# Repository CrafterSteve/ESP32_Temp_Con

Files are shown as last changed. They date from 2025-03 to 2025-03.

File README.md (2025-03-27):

# ESP32_Temp_Con
An temperture control device, based on ESP32. With custom PCB board, it can fit an ESP32-DevKit as controller, DAC and ADC is done on board, as well as, a 5 to +-12v power supply.

## Notes:
项目中 ./main/my_spiffs/ 目录下的文件会通过命令，全部烧写的分区 label 的 flash 中。

创建自定义空间前，先做配置：
used "idf.py menuconfig" to change partition table to csv.

created "partitions.csv" with 256KB of spiffs as "/storage": （以下是"partitions.csv"文件应该包含的内容）
nvs, data, nvs, 0x9000, 0x6000
phy_init, data, phy, 0xf000, 0x1000
factory, app, factory, 0x10000, 0x100000
storage, data, spiffs, 0x110000, 0x40000

## SPIFFS指令：
使用时注意 python 工具的路径。“./” 代表本项目的根目录

python D:\esp\v5.2.1\esp-idf\components\partition_table\gen_esp32part.py .\partitions.csv .\partitions.bin                                      // 从csv生成分区文件

idf.py partition-table-flash                                                                                                                    // 烧录分区文件

python D:\esp\v5.2.1\esp-idf\components\spiffs\spiffsgen.py 0x40000 D:\esp_projects\dactest_2.1\main\my_spiffs my_spiffs_img                    // 创建SPIFFS镜像文件

python D:\esp\v5.2.1\esp-idf\components\partition_table\parttool.py -p COM3 write_partition --partition-name storage --input .\my_spiffs_img    // 写入esp32

## 程序调用
in code: base_path = "/storage"     // esp32内文件目录
"/storage/bmp_test.bmp" 为存入的文件
FILE *file = fopen("/storage/bmp_test.bmp", "rb");  // 如此打开flash上的文件
可通过 esp_spiffs_info(spiffs_conf.partition_label, &total, &used); 查看占用，检查是否写入。

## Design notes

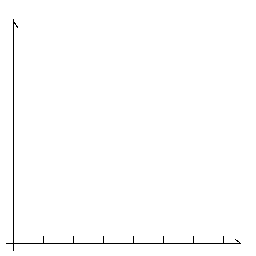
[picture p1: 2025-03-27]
main/my_spiffs/bmp_3.bmp

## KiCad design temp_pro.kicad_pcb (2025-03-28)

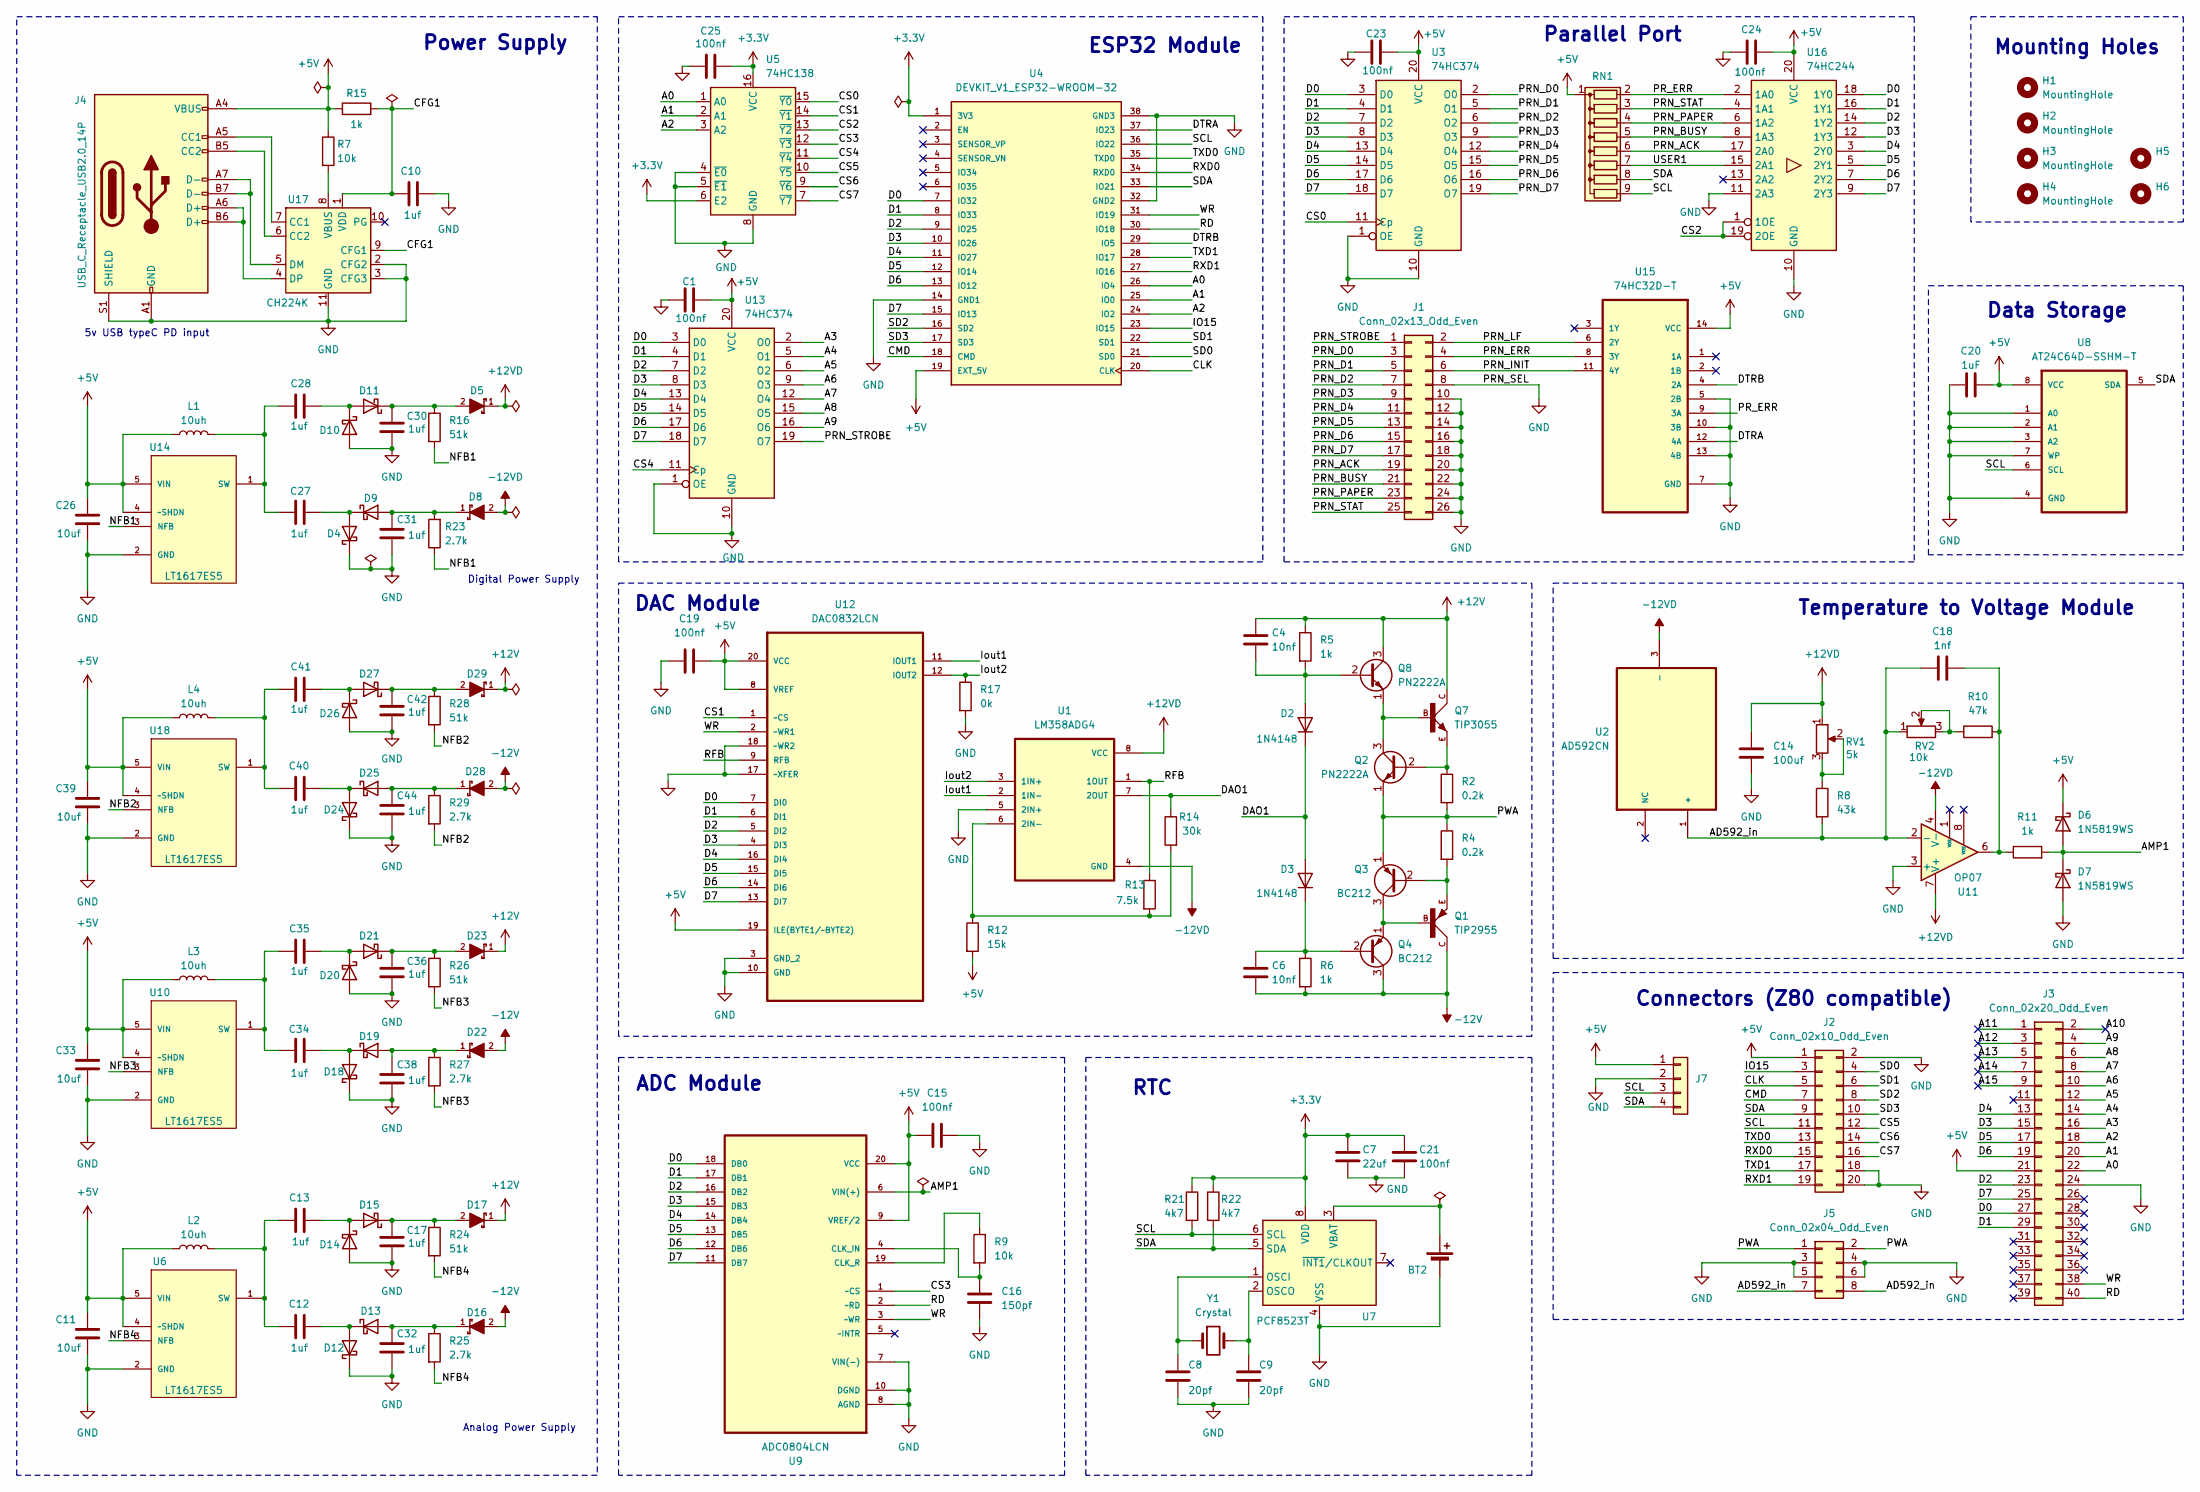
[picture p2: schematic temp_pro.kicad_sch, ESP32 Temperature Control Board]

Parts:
BT2: Battery_Cell; TE_796136-1
C1, C15, C19, C23, C24, C25: 100nf; C_0805_2012Metric
C4, C6: 10nf; C_Disc_D5.0mm_W2.5mm_P5.00mm
C7: 22uf; C_0805_2012Metric
C8, C9: 20pf; C_0805_2012Metric
C10: 1uf; C_0603_1608Metric
C11, C26, C33, C39: 10uf; C_0603_1608Metric
C12, C13, C17, C27, C28, C30, C31, C32, C34, C35, C36, C38, C40, C41, C42, C44: 1uf; C_0805_2012Metric
C14: 100uf; C_0805_2012Metric
C16: 150pf; C_0603_1608Metric
C18: 1nf; C_0805_2012Metric
C20: 1uF; C_0603_1608Metric
C21: 100nf; C_0603_1608Metric
D2, D3: 1N4148; D_DO-35_SOD27_P7.62mm_Horizontal
D4, D9, D10, D11, D12, D13, D14, D15, D18, D19, D20, D21, D24, D25, D26, D27: 1N5822; DIOM5025X220N
D5, D8, D16, D17, D22, D23, D28, D29: SS54-HF; DIOM5025X220N; MOUSER_PART_NUMBER 750-SS54-HF
D6, D7: 1N5819WS; D_SOD-323_HandSoldering
H1, H2, H3, H4, H5, H6: MountingHole; MountingHole_3.2mm_M3_ISO14580
J1: Conn_02x13_Odd_Even; PinHeader_2x13_P2.54mm_Vertical
J2: Conn_02x10_Odd_Even; PinHeader_2x10_P2.54mm_Vertical
J3: Conn_02x20_Odd_Even; PinHeader_2x20_P2.54mm_Vertical
J4: USB_C_Receptacle_USB2.0_14P; USB_C_Receptacle_GCT_USB4105-xx-A_16P_TopMnt_Horizontal
J5: Conn_02x04_Odd_Even; PinHeader_2x04_P2.54mm_Vertical
J7: Conn_01x04; PinHeader_1x04_P2.54mm_Vertical
L1, L2, L3, L4: 10uh; L_Bourns_SRP7028A_7.3x6.6mm
Q1: TIP2955; TOP3AV
Q2, Q8: PN2222A; TO-92_Inline
Q3, Q4: BC212; TO-92_Inline
Q7: TIP3055; TOP3AV
R2, R4: 0.2k; R_Axial_DIN0516_L15.5mm_D5.0mm_P20.32mm_Horizontal
R5, R6: 1k; R_Axial_DIN0207_L6.3mm_D2.5mm_P7.62mm_Horizontal
R7, R9: 10k; R_0603_1608Metric
R8: 43k; R_0805_2012Metric
R10: 47k; R_0805_2012Metric
R11, R15: 1k; R_0805_2012Metric
R12: 15k; R_0805_2012Metric
R13: 7.5k; R_0805_2012Metric
R14: 30k; R_0805_2012Metric
R16, R24, R26, R28: 51k; R_0603_1608Metric
R17: 0k; R_0603_1608Metric
R21, R22: 4k7; R_0603_1608Metric
R23, R25, R27, R29: 2.7k; R_0603_1608Metric
RN1: R_Network08; R_Array_SIP9
RV1: 5k; Potentiometer_Vishay_T93YA_Vertical
RV2: 10k; Potentiometer_Vishay_T93YA_Vertical
U1: LM358ADG4; DIP-8_W7.62mm_Socket
U2: AD592CN; TO-92L; MPN AD592CN
U3, U13: 74HC374; DIP-20_W7.62mm_Socket
U4: DEVKIT_V1_ESP32-WROOM-32; MODULE_DEVKIT_V1_ESP32-WROOM-32; PARTREV N/A
U5: 74HC138; DIP-16_W7.62mm_Socket
U6, U10, U14, U18: LT1617ES5; SOT-23-6; MPN LT1617ES5#PBF
U7: PCF8523T; SOIC-8_3.9x4.9mm_P1.27mm
U8: AT24C64D-SSHM-T; DIP-8_W7.62mm_Socket; MPN AT24C64D-SSHM-T
U9: ADC0804LCN; DIP-20_W7.62mm_Socket; MPN ADC0804LCN
U11: OP07; DIP-8_W7.62mm_Socket
U12: DAC0832LCN; DIP-20_W7.62mm_Socket; MPN DAC0832LCN
U15: 74HC32D-T; DIP-14_W7.62mm_Socket; MPN 74HC32D-T
U16: 74HC244; DIP-20_W7.62mm_Socket
U17: CH224K; SSOP-10-1EP_3.9x4.9mm_P1mm_EP2.1x3.3mm
Y1: Crystal; Crystal_C38-LF_D3.0mm_L8.0mm_Horizontal

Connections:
+3.3V: C7.1, C21.1, C25.2, R21.1, R22.1, U4.1 (3V3), U5.6 (E2), U5.16 (VCC), U7.8 (VDD)
+5V: C1.2, C11.1, C15.2, C19.2, C20.2, C23.2, C24.2, C26.1, C33.1, C39.1, D6.1 (K), J2.1, J3.21, J4.A4 (VBUS), J4.A9 (VBUS), J4.B4 (VBUS), J4.B9 (VBUS), J7.1, L1.1, L2.1, L3.1, L4.1, R7.1, R12.2, R15.1, RN1.1 (common), U3.20 (VCC), U4.19 (EXT_5V), U6.4 (~SHDN), U6.5 (VIN), U8.8 (VCC), U9.9 (VREF/2), U9.20 (VCC), U10.4 (~SHDN), U10.5 (VIN), U12.8 (VREF), U12.19 (ILE(BYTE1/~BYTE2)), U12.20 (VCC), U13.20 (VCC), U14.4 (~SHDN), U14.5 (VIN), U15.14 (VCC), U16.20 (VCC), U18.4 (~SHDN), U18.5 (VIN)
+12V: C4.1, D17.1, D23.1, D29.1, Q7.C, Q8.3 (C), R5.1
+12VD: C14.1, D5.1, RV1.1, U1.8 (VCC), U11.7 (V+)
-12V: C6.2, D16.2, D22.2, D28.2, Q1.C, Q4.3 (C), R6.2
-12VD: D8.2, U1.4 (GND), U2.3 (-), U11.4 (V-)
/A0: J3.22, U4.26 (IO4), U5.1 (A0)
/A1: J3.20, U4.25 (IO0), U5.2 (A1)
/A2: J3.18, U4.24 (IO2), U5.3 (A2)
/A3: J3.16, U13.2 (O0)
/A4: J3.14, U13.5 (O1)
/A5: J3.12, U13.6 (O2)
/A6: J3.10, U13.9 (O3)
/A7: J3.8, U13.12 (O4)
/A8: J3.6, U13.15 (O5)
/A9: J3.4, U13.16 (O6)
/A10: J3.2
/A11: J3.1
/A12: J3.3
/A13: J3.5
/A14: J3.7
/A15: J3.9
/AD592_in: C18.1, J5.7, J5.8, R8.2, RV2.1, U2.1 (+), U11.2 (-)
/AMP1: D6.2 (A), D7.1 (K), R11.2, U9.6 (VIN(+))
/CFG1: C10.1, R15.2, U17.1 (VDD), U17.9 (CFG1)
/CLK: J2.5, U4.20 (CLK)
/CMD: J2.7, U4.18 (CMD)
/CS0: U3.11 (Cp), U5.15 (~Y0)
/CS1: U5.14 (~Y1), U12.1 (~CS)
/CS2: U5.13 (~Y2), U16.1 (1OE), U16.19 (2OE)
/CS3: U5.12 (~Y3), U9.1 (~CS)
/CS4: U5.11 (~Y4), U13.11 (Cp)
/CS5: J2.12, U5.10 (~Y5)
/CS6: J2.14, U5.9 (~Y6)
/CS7: J2.16, U5.7 (~Y7)
/D0: J3.27, U3.3 (D0), U4.7 (IO32), U9.18 (DB0), U12.7 (DI0), U13.3 (D0), U16.18 (1Y0)
/D1: J3.29, U3.4 (D1), U4.8 (IO33), U9.17 (DB1), U12.6 (DI1), U13.4 (D1), U16.16 (1Y1)
/D2: J3.23, U3.7 (D2), U4.9 (IO25), U9.16 (DB2), U12.5 (DI2), U13.7 (D2), U16.14 (1Y2)
/D3: J3.15, U3.8 (D3), U4.10 (IO26), U9.15 (DB3), U12.4 (DI3), U13.8 (D3), U16.12 (1Y3)
/D4: J3.13, U3.13 (D4), U4.11 (IO27), U9.14 (DB4), U12.16 (DI4), U13.13 (D4), U16.3 (2Y0)
/D5: J3.17, U3.14 (D5), U4.12 (IO14), U9.13 (DB5), U12.15 (DI5), U13.14 (D5), U16.5 (2Y1)
/D6: J3.19, U3.17 (D6), U4.13 (IO12), U9.12 (DB6), U12.14 (DI6), U13.17 (D6), U16.7 (2Y2)
/D7: J3.25, U3.18 (D7), U4.15 (IO13), U9.11 (DB7), U12.13 (DI7), U13.18 (D7), U16.9 (2Y3)
/DAO1: D2.1 (K), D3.2 (A), R14.1, U1.7 (2OUT)
/DTRA: U4.37 (IO23), U15.12 (4A)
/DTRB: U4.29 (IO5), U15.4 (2A)
/IO15: J2.3, U4.23 (IO15)
/Iout1: U1.2 (1IN-), U12.11 (IOUT1)
/Iout2: R17.1, U1.3 (1IN+), U12.12 (IOUT2)
/NFB1: R16.2, R23.1, U14.3 (NFB)
/NFB2: R28.2, R29.2, U18.3 (NFB)
/NFB3: R26.2, R27.2, U10.3 (NFB)
/NFB4: R24.2, R25.2, U6.3 (NFB)
/PRN_ACK: J1.19, RN1.6 (R5), U16.17 (2A0)
/PRN_BUSY: J1.21, RN1.5 (R4), U16.8 (1A3)
/PRN_D0: J1.3, U3.2 (O0)
/PRN_D1: J1.5, U3.5 (O1)
/PRN_D2: J1.7, U3.6 (O2)
/PRN_D3: J1.9, U3.9 (O3)
/PRN_D4: J1.11, U3.12 (O4)
/PRN_D5: J1.13, U3.15 (O5)
/PRN_D6: J1.15, U3.16 (O6)
/PRN_D7: J1.17, U3.19 (O7)
/PRN_ERR: J1.4, U15.8 (3Y)
/PRN_INIT: J1.6, U15.11 (4Y)
/PRN_LF: J1.2, U15.6 (2Y)
/PRN_PAPER: J1.23, RN1.4 (R3), U16.6 (1A2)
/PRN_STAT: J1.25, RN1.3 (R2), U16.4 (1A1)
/PRN_STROBE: J1.1, U13.19 (O7)
/PR_ERR: RN1.2 (R1), U15.9 (3A), U16.2 (1A0)
/PWA: J5.1, J5.2, Q2.1 (E), Q3.1 (E), R2.2, R4.1
/RD: J3.40, U4.30 (IO18), U9.2 (~RD)
/RFB: R13.1, U1.1 (1OUT), U12.9 (RFB)
/RXD0: J2.15, U4.34 (RXD0)
/RXD1: J2.19, U4.27 (IO16)
/SCL: J2.11, J7.3, R21.2, RN1.9 (R8), U4.36 (IO22), U7.6 (SCL), U8.6 (SCL)
/SD0: J2.4, U4.21 (SD0)
/SD1: J2.6, U4.22 (SD1)
/SD2: J2.8, U4.16 (SD2)
/SD3: J2.10, U4.17 (SD3)
/SDA: J2.9, J7.4, R22.2, RN1.8 (R7), U4.33 (IO21), U7.5 (SDA), U8.5 (SDA)
/TXD0: J2.13, U4.35 (TXD0)
/TXD1: J2.17, U4.28 (IO17)
/USER1: RN1.7 (R6), U16.15 (2A1)
/WR: J3.38, U4.31 (IO19), U9.3 (~WR), U12.2 (~WR1)
GND: BT2.2 (-), C1.1, C7.2, C8.2, C9.2, C10.2, C11.2, C14.2, C15.1, C16.2, C17.2, C19.1, C20.1, C21.2, C23.1, C24.1, C25.1, C26.2, C30.2, C31.2, C32.2, C33.2, C36.2, C38.2, C39.2, C42.2, C44.2, D4.1 (K), D7.2 (A), D10.2 (A), D12.1 (K), D14.2 (A), D18.1 (K), D20.2 (A), D24.1 (K), D26.2 (A), J1.8, J1.10, J1.12, J1.14, J1.16, J1.18, J1.20, J1.22, J1.24, J1.26, J2.2, J2.18, J2.20, J3.24, J4.A1 (GND), J4.A12 (GND), J4.B1 (GND), J4.B12 (GND), J4.S1 (SHIELD), J5.3, J5.4, J5.5, J5.6, J7.2, R17.2, U1.5 (2IN+), U3.1 (OE), U3.10 (GND), U4.14 (GND1), U4.32 (GND2), U4.38 (GND3), U5.4 (~E0), U5.5 (~E1), U5.8 (GND), U6.2 (GND), U7.4 (VSS), U8.1 (A0), U8.2 (A1), U8.3 (A2), U8.4 (GND), U8.7 (WP), U9.7 (VIN(-)), U9.8 (AGND), U9.10 (DGND), U10.2 (GND), U11.3 (+), U12.3 (GND_2), U12.10 (GND), U12.17 (~XFER), U12.18 (~WR2), U13.1 (OE), U13.10 (GND), U14.2 (GND), U15.5 (2B), U15.7 (GND), U15.10 (3B), U15.13 (4B), U16.10 (GND), U16.11 (2A3), U17.2 (CFG2), U17.3 (CFG3), U17.11 (GND), U18.2 (GND)
unnamed: BT2.1 (+), U7.3 (VBAT)
unnamed: C18.2, R10.2, R11.1, U11.6
unnamed: C4.2, D2.2 (A), Q8.2 (B), R5.2
unnamed: C6.1, D3.1 (K), Q4.2 (B), R6.1
unnamed: C27.2, D4.2 (A), D9.1 (K)
unnamed: C31.1, D8.1, D9.2 (A), R23.2
unnamed: C28.1, D10.1 (K), D11.2 (A)
unnamed: C30.1, D5.2, D11.1 (K), R16.1
unnamed: C12.2, D12.2 (A), D13.1 (K)
unnamed: C32.1, D13.2 (A), D16.1, R25.1
unnamed: C13.1, D14.1 (K), D15.2 (A)
unnamed: C17.1, D15.1 (K), D17.2, R24.1
unnamed: C34.2, D18.2 (A), D19.1 (K)
unnamed: C38.1, D19.2 (A), D22.1, R27.1
unnamed: C35.1, D20.1 (K), D21.2 (A)
unnamed: C36.1, D21.1 (K), D23.2, R26.1
unnamed: C40.2, D24.2 (A), D25.1 (K)
unnamed: C44.1, D25.2 (A), D28.1, R29.1
unnamed: C41.1, D26.1 (K), D27.2 (A)
unnamed: C42.1, D27.1 (K), D29.2, R28.1
unnamed: J4.A5 (CC1), U17.7 (CC1)
unnamed: J4.B5 (CC2), U17.6 (CC2)
unnamed: Q2.2 (B), Q7.E, R2.1
unnamed: Q2.3 (C), Q7.B, Q8.1 (E)
unnamed: Q1.E, Q3.2 (B), R4.2
unnamed: Q1.B, Q3.3 (C), Q4.1 (E)
unnamed: R8.1, RV1.2, RV1.3
unnamed: R10.1, RV2.2, RV2.3
unnamed: R12.1, R13.2, R14.2, U1.6 (2IN-)
unnamed: C12.1, C13.2, L2.2, U6.1 (SW)
unnamed: C8.1, U7.1 (OSCI), Y1.1
unnamed: C9.1, U7.2 (OSCO), Y1.2
unnamed: C16.1, R9.2, U9.4 (CLK_IN)
unnamed: R9.1, U9.19 (CLK_R)
unnamed: C34.1, C35.2, L3.2, U10.1 (SW)
unnamed: C27.1, C28.2, L1.2, U14.1 (SW)
unnamed: J4.A7 (D-), J4.B7 (D-), U17.5 (DM)
unnamed: J4.A6 (D+), J4.B6 (D+), U17.4 (DP)
unnamed: R7.2, U17.8 (VBUS)
unnamed: C40.1, C41.2, L4.2, U18.1 (SW)

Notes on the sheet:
5v USB typeC PD input
ESP32 Module
Digital Power Supply
Data Storage
ADC Module
RTC
Temperature to Voltage Module
DAC Module
Mounting Holes
Parallel Port
Analog Power Supply
Power Supply
Connectors (Z80 compatible)

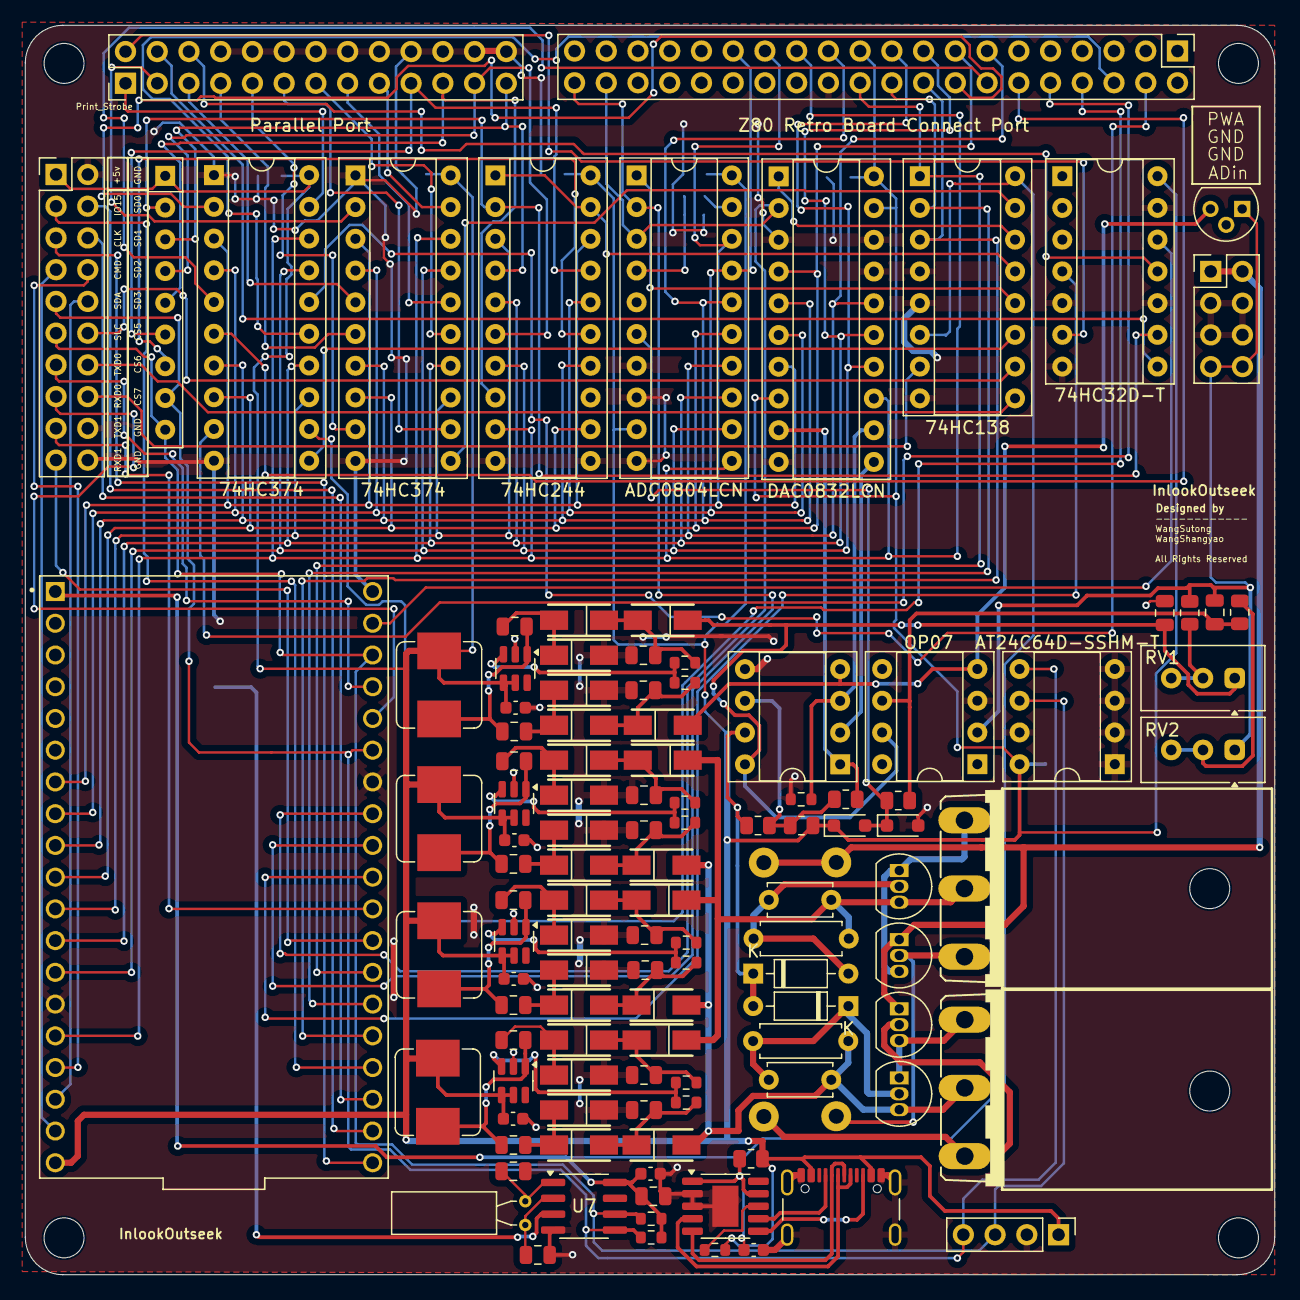
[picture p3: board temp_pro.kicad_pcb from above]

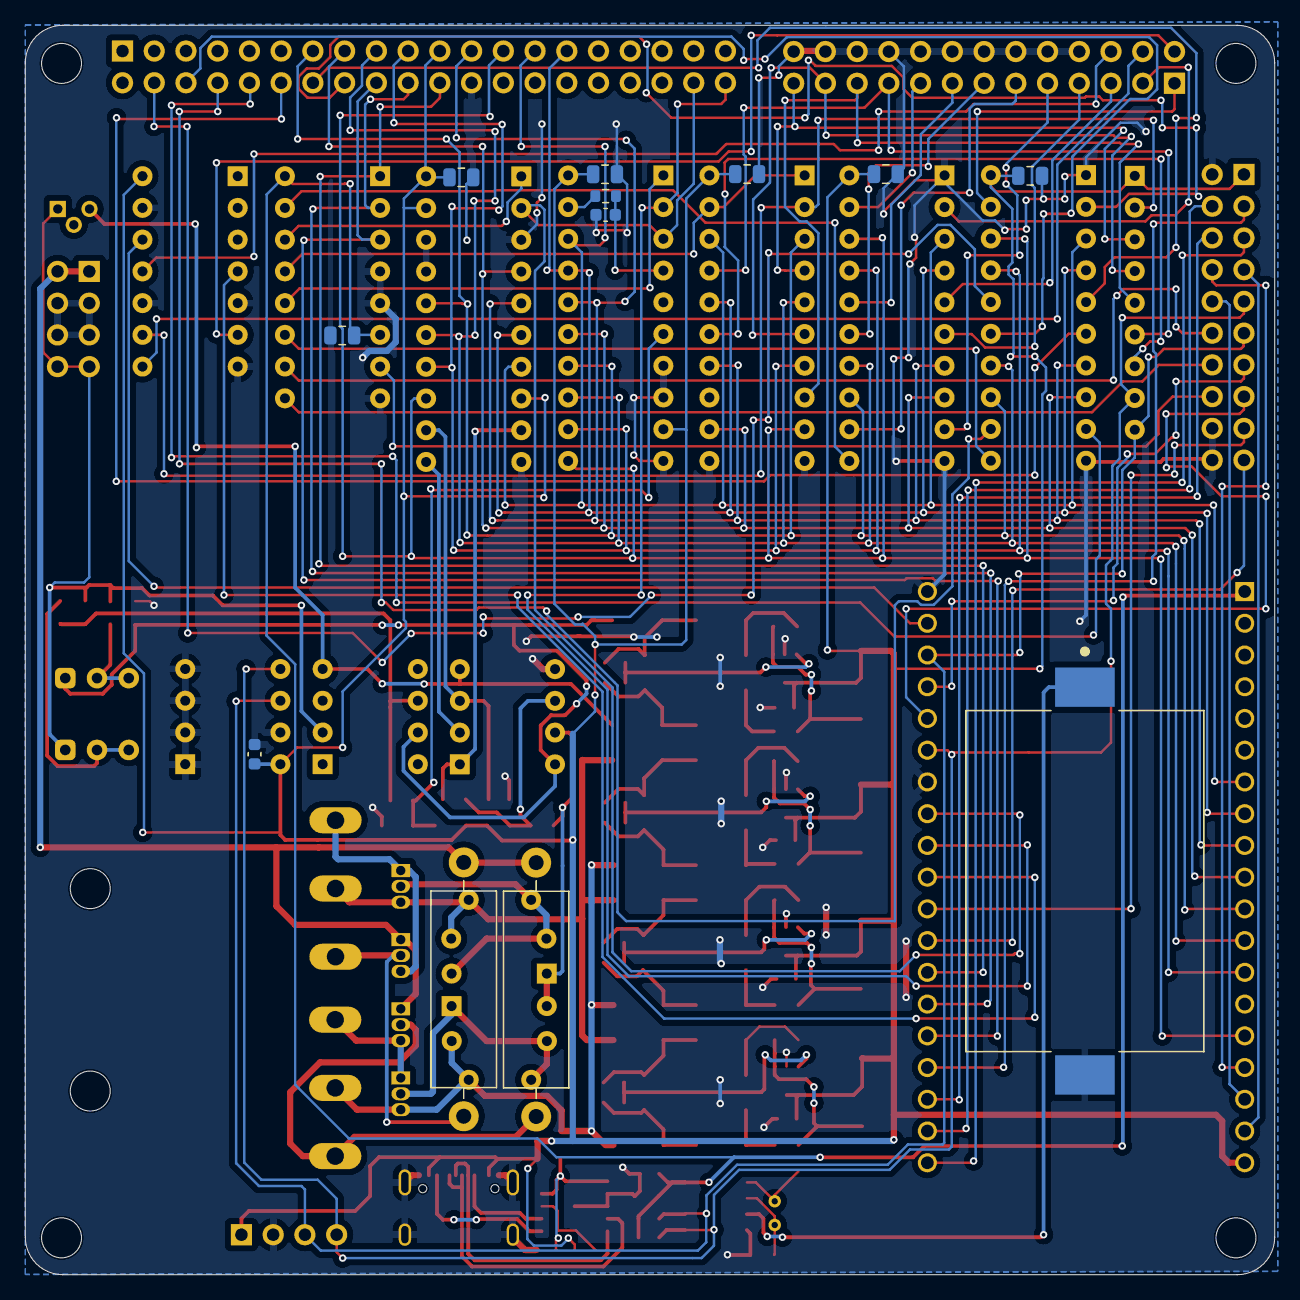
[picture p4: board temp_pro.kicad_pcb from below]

Board: 2 copper layers, 100.0 x 100.0 mm, 134 parts (12 on the bottom side), 120 nets.

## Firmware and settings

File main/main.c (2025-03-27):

#include "./device_init.h"
#include "./printer.h"
#include <stdlib.h>


esp_err_t ret;
uint8_t read_data[20];
uint8_t RTC_time[7] = {0};
uint8_t ADC_value;
uint8_t read_int;
uint8_t hour, minute, second, year, month, day, second_old;
uint16_t epr_addr = 0;

char str[20];
char adc_str[16];
uint8_t adc_buf[240];
char time_str[25];
char write_str[16];
uint8_t write_data[16];

uint8_t count = 0;
int loop_count = 0;
uint8_t time_count = 0;
uint8_t time_count_old = 0;


void app_main(void)
{
    // 设备初始化
    init_gpio();
    //lpt_init(); 
    spiffs_init();
    i2c_master_init();
    i2c_scan();             // i2c 总线地址扫描
    OLEDDisplay_t *oled = OLEDDisplay_init(I2C_MASTER_NUM,0x78,SDA,SCL);
    RTC_set();              // RTC 初始化、时间设置
    
    // Intro Screen-----------------------------------------start
    OLEDDisplay_drawRect(oled,6,32,20,20);
	OLEDDisplay_display(oled);
	vTaskDelay(500 / portTICK_PERIOD_MS);

    OLEDDisplay_setTextAlignment(oled,TEXT_ALIGN_CENTER);
    OLEDDisplay_setFont(oled,ArialMT_Plain_24);
    OLEDDisplay_drawString(oled,64, 00, "Temp_CON");
	OLEDDisplay_display(oled);
	vTaskDelay(500 / portTICK_PERIOD_MS);

    OLEDDisplay_setFont(oled,ArialMT_Plain_10);
    OLEDDisplay_drawString(oled,64, 40, "----------");
	OLEDDisplay_display(oled);
    // Intro Screen------------------------------------------end

    // erase eeprom data
    for(int i = 0; i < 240; i++){
        sprintf(write_str, "%d", 14);
        for(int i = 0; i < 16; i++){
            write_data[i] = (uint8_t)write_str[i];
        }
        ret = write_to_eeprom((uint16_t)(i*16), write_data, 16);
        if (ret != ESP_OK) {ESP_LOGE("I2C", "eeprom read faild: %s", esp_err_to_name(ret));}
        else{ESP_LOGI("I2C_storage", "write data: %s", write_data);}
    }

    while (1) {
        spiffs_info();

        vTaskDelay(pdMS_TO_TICKS(50));

        chip_select(1);
        set_dataBus(255);                                   // set voltage -9 to 9v (0-255)

        chip_select(3);
        ADC_value = read_dataBus();                         // read voltage
        sprintf(adc_str, "ADC: %d", ADC_value);

        rtc_read(RTC_time);
        second = RTC_time[0];
        sprintf(time_str, "%02X:%02X:%02X 20%02X.%02X.%02X", 
            RTC_time[2], RTC_time[1], RTC_time[0], RTC_time[6], RTC_time[5], RTC_time[3]);
        
        // 
        if(epr_addr > 240*16){
            epr_addr = 0;
        }
        
        // gloable timer counter
        if(second != second_old){
            sprintf(write_str, "%d", ADC_value);
            for(int i = 0; i < 16; i++){
                write_data[i] = (uint8_t)write_str[i];
            }
            ret = write_to_eeprom(epr_addr, write_data, 16);
            if (ret != ESP_OK) {ESP_LOGE("I2C", "eeprom read faild: %s", esp_err_to_name(ret));}
            else{ESP_LOGI("I2C_storage", "write data: %s", write_data);}

            // display refresh every second.
            OLEDDisplay_clear(oled);
            OLEDDisplay_setFont(oled,ArialMT_Plain_16);
            OLEDDisplay_drawString(oled,64, 25, adc_str);       // ADC value display

            OLEDDisplay_setFont(oled,ArialMT_Plain_10);
            OLEDDisplay_drawString(oled,64, 00, time_str);      // RTC time display

            OLEDDisplay_display(oled);
 
            second_old = second;
            time_count++;
        }
        epr_addr = epr_addr + 16;

        // print temp curve every 30s (actually about 46s, printing takes time.)
        if(time_count > time_count_old + 30){
            for(int i = 0; i < 240; i++){
                ret = read_from_eeprom((uint16_t)(i*16), read_data, 16);
                if (ret != ESP_OK) {ESP_LOGE("I2C", "eeprom read faild: %s", esp_err_to_name(ret));}
                else{ESP_LOGI("I2C_storage", "read data: %s", read_data);}
                adc_buf[i] = atoi((char*)read_data);
                ESP_LOGI("I2C_storage", "adc_data_buffer: %d", adc_buf[i]);
            }

            OLEDDisplay_clear(oled);
            OLEDDisplay_setFont(oled,ArialMT_Plain_16);
            OLEDDisplay_drawString(oled,64, 25, "Printing...");
            OLEDDisplay_display(oled);

            lpt_send_string(time_str);
            print_image("/storage/bmp.txt", adc_buf);
            time_count_old = time_count;
        }

        

        //char lpt_str[25];
        //sprintf(lpt_str, "hello printer");
        //lpt_send_string(lpt_str);
        

    }
}

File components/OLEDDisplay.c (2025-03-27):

/**
 * The MIT License (MIT)
 *
 * Copyright (c) 2018 by ThingPulse, Daniel Eichhorn
 * Copyright (c) 2018 by Fabrice Weinberg
 * Copyright (c) 2019 by Helmut Tschemernjak - www.radioshuttle.de
 * Copyright (c) 2020 by Brad Goodman - www.bradgoodman.com
 *
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
 * ThingPulse invests considerable time and money to develop these open source libraries.
 * Please support us by buying our products (and not the clones) from
 * https://thingpulse.com
 *
 */

 /*
  * TODO Helmut
  * - test/finish dislplay.printf() on mbed-os
  * - Finish _putc with drawLogBuffer when running display
  */

#include "esp_log.h"
#include <stdint.h>
#include <stdlib.h>
#include <string.h>
#include "sdkconfig.h"
#include "OLEDDisplay.h"
#include "driver/i2c.h"

#define WRITE_BIT I2C_MASTER_WRITE              /*!< I2C master write */
#define READ_BIT I2C_MASTER_READ                /*!< I2C master read */
#define ACK_CHECK_EN 0x1                        /*!< I2C master will check ack from slave*/
#define ACK_CHECK_DIS 0x0                       /*!< I2C master will not check ack from slave */
#define ACK_VAL 0x0                             /*!< I2C ack value */
#define NACK_VAL 0x1                            /*!< I2C nack value */

static inline uint16_t _max(uint16_t x,uint16_t y) { if (x>y) return (x); return(y);}
static inline uint16_t _min(uint16_t x,uint16_t y) { if (x<y) return (x); return(y);}

#define TAG "OLED"

OLEDDisplay_t * OLEDDisplay_alloc() {

	OLEDDisplay_t *oled = malloc(sizeof(OLEDDisplay_t));
	if (!oled)
		return 0L;
	oled->width = 128;
	oled->height = 64;
	oled->displayBufferSize = oled->width * oled->height / 8;
	oled->color = WHITE;
	oled->geometry = GEOMETRY_128_64;
	oled->textAlignment = TEXT_ALIGN_LEFT;
	oled->fontData = ArialMT_Plain_10;
	oled->fontTableLookupFunction = DefaultFontTableLookup;
	oled->buffer = NULL;
#ifdef OLEDDISPLAY_DOUBLE_BUFFER
	oled->buffer_back = NULL;
#endif
	return (oled);
}

void OLEDDisplay_free(OLEDDisplay_t *oled) {
  if (oled)
    free(oled);
}

static int OLEDDisplay_getBufferOffset(OLEDDisplay_t *oled) {return(0);}
int OLEDDisplay_allocateBuffer(OLEDDisplay_t *oled) {

  oled->logBufferSize = 0;
  oled->logBufferFilled = 0;
  oled->logBufferLine = 0;
  oled->logBufferMaxLines = 0;
  oled->logBuffer = NULL;

  if(oled->buffer==NULL) {
    oled->buffer = (uint8_t*) malloc((sizeof(uint8_t) * oled->displayBufferSize) + OLEDDisplay_getBufferOffset(oled));
    oled->buffer += OLEDDisplay_getBufferOffset(oled);

    if(!oled->buffer) {
      DEBUG_OLEDDISPLAY("[OLEDDISPLAY][init] Not enough memory to create display\n");
      return -1;
    }
  }

  #ifdef OLEDDISPLAY_DOUBLE_BUFFER
  if(oled->buffer_back==NULL) {
    oled->buffer_back = (uint8_t*) malloc((sizeof(uint8_t) * oled->displayBufferSize) + OLEDDisplay_getBufferOffset(oled));
    oled->buffer_back += OLEDDisplay_getBufferOffset(oled);

    if(!oled->buffer_back) {
      DEBUG_OLEDDISPLAY("[OLEDDISPLAY][init] Not enough memory to create back buffer\n");
      free(oled->buffer - OLEDDisplay_getBufferOffset(oled));
      return -1;
    }
  }
  #endif

  return 0;
}

OLEDDisplay_t * OLEDDisplay_init(int port, int addr, int sda, int scl)
{
		OLEDDisplay_t *oled = OLEDDisplay_alloc();
		if (!oled) {
			ESP_LOGW(TAG, "OLED Allocation failed\n");
			return 0L;
		}
    
		oled->i2c_sda_gpio = sda;
		oled->i2c_scl_gpio = scl;
		oled->i2c_port = port;
		oled->i2c_addr = addr;

		if(OLEDDisplay_allocateBuffer(oled)) {
			ESP_LOGW(TAG, "OLED Display Buffer Allocation failed\n");
			return 0L;
		}

		OLEDDisplay_sendInitCommands(oled);
		OLEDDisplay_resetDisplay(oled);
		return (oled);
		
}

#define BKG_ACK_CHECK 0 /* ACK_CHECK_EN */
static void OLEDDisplay_sendCommand(OLEDDisplay_t *oled, uint8_t opcode)
{
    i2c_cmd_handle_t cmd = i2c_cmd_link_create();
    i2c_master_start(cmd);
    i2c_master_write_byte(cmd, oled->i2c_addr | WRITE_BIT,  BKG_ACK_CHECK  );
    i2c_master_write_byte(cmd, 0x80, BKG_ACK_CHECK  );
    i2c_master_write_byte(cmd, opcode,  BKG_ACK_CHECK  );
    i2c_master_stop(cmd);
    esp_err_t ret = i2c_master_cmd_begin(oled->i2c_port, cmd, 1000 / portTICK_PERIOD_MS);
    i2c_cmd_link_delete(cmd);
}

static void OLEDDisplay_beginPayload(OLEDDisplay_t *oled)
{
    i2c_cmd_handle_t cmd = i2c_cmd_link_create();
    i2c_master_start(cmd);
    i2c_master_write_byte(cmd, oled->i2c_addr | WRITE_BIT,  BKG_ACK_CHECK  );
		oled->i2c_cmd = cmd;
}

static void OLEDDisplay_i2cwrite(OLEDDisplay_t *oled,uint8_t d)
{
    i2c_cmd_handle_t cmd = oled->i2c_cmd;
    i2c_master_write_byte(cmd, d, BKG_ACK_CHECK  );
}

static esp_err_t OLEDDisplay_endPayload(OLEDDisplay_t *oled) {
    i2c_cmd_handle_t cmd = oled->i2c_cmd;
    i2c_master_stop(cmd);
    esp_err_t ret = i2c_master_cmd_begin(oled->i2c_port, cmd, 1000 / portTICK_PERIOD_MS);
    i2c_cmd_link_delete(cmd);
    return ret;
}
static esp_err_t OLEDDisplay_sendPayload(OLEDDisplay_t *oled, uint8_t *buf, size_t size)
{
    i2c_cmd_handle_t cmd = i2c_cmd_link_create();
    i2c_master_start(cmd);
    i2c_master_write_byte(cmd, oled->i2c_addr | WRITE_BIT,  BKG_ACK_CHECK  );
    i2c_master_write_byte(cmd, 0x40, BKG_ACK_CHECK  );
    i2c_master_write(cmd, buf, size, BKG_ACK_CHECK);
    i2c_master_stop(cmd);
    esp_err_t ret = i2c_master_cmd_begin(oled->i2c_port, cmd, 1000 / portTICK_PERIOD_MS);
    i2c_cmd_link_delete(cmd);
    return ret;
}
void OLEDDisplay_end(OLEDDisplay_t *oled) {
  if (oled->buffer) { free(oled->buffer - OLEDDisplay_getBufferOffset(oled)); oled->buffer = NULL; }
  #ifdef OLEDDISPLAY_DOUBLE_BUFFER
  if (oled->buffer_back) { free(oled->buffer_back - OLEDDisplay_getBufferOffset(oled)); oled->buffer_back = NULL; }
  #endif
  if (oled->logBuffer != NULL) { free(oled->logBuffer); oled->logBuffer = NULL; }
}

void OLEDDisplay_resetDisplay(OLEDDisplay_t *oled) {
  OLEDDisplay_clear(oled);
  #ifdef OLEDDISPLAY_DOUBLE_BUFFER
  memset(oled->buffer_back, 1, oled->displayBufferSize);
  #endif
  OLEDDisplay_display(oled);
}

void OLEDDisplay_setColor(OLEDDisplay_t *oled, OLEDDISPLAY_COLOR color) {
  oled->color = color;
}

OLEDDISPLAY_COLOR OLEDDisplay_getColor(OLEDDisplay_t *oled) {
  return oled->color;
}

void OLEDDisplay_setPixel(OLEDDisplay_t *oled, int16_t x, int16_t y) {
  if (x >= 0 && x < oled->width && y >= 0 && y < oled->height) {
    switch (oled->color) {
      case WHITE:   oled->buffer[x + (y / 8) * oled->width] |=  (1 << (y & 7)); break;
      case BLACK:   oled->buffer[x + (y / 8) * oled->width] &= ~(1 << (y & 7)); break;
      case INVERSE: oled->buffer[x + (y / 8) * oled->width] ^=  (1 << (y & 7)); break;
    }
  }
}
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

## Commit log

2025-03-27 Functional codes with basic functions.
    [partitions.csv]
2025-03-28 PCB files, still bugs to be fixed in next version
    [temp_pro-B_Cu.gbr, temp_pro-B_Mask.gbr, temp_pro-B_Paste.gbr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]

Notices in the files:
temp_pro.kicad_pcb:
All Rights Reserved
